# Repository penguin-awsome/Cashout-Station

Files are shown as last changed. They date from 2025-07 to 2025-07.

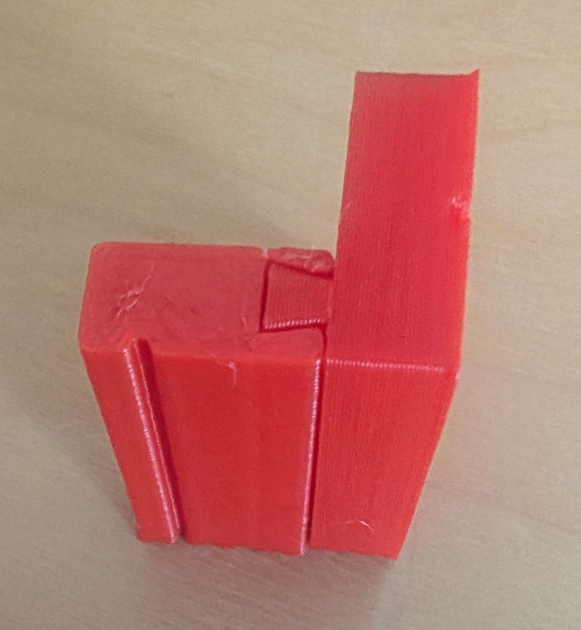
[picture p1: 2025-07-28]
Project Photos/Dovetail Test.jpg

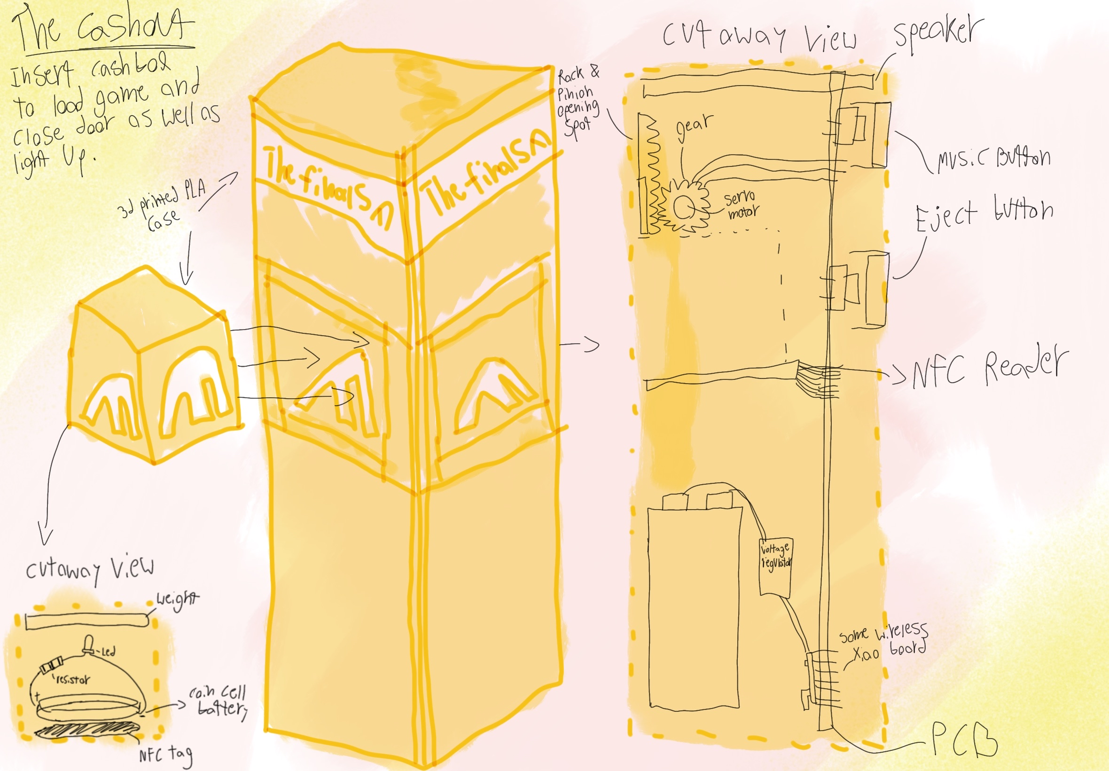
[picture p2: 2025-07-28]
Project Photos/Initial Sketch.png

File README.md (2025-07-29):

# Cashout-Station

Hello everybody, this is my latest project: The Cashout Station!

This project is inspired from my favorite video game,'The Finals', a team based FPS shooter, as well as one of my friends projects: https://github.com/jamdotjar/ULTRATERM which is another terminal inspired from a video game. In the game, the cashout is the objective point, where you insert the 'Cashbox' to begin an objective point. In my version, you insert the cahbox to launch the game and play some of the game music.

It uses a NFC Detector to detect when the cashbox has been inserted via an NFC tag, and uses a servo motor to pull the box in and close the opening for th ebox as well. It is powered by a 9v battery being stepped down to 5v to run a Xiao ESP32-C6 which is the brains of the operation. It also includes some LEDs for flair and a speaker and mini amp for the sound. It also has two buttons, one for opening up the insertion slot and one for ejecting it.

Here are some photos of the finished design:

Finished Schematic
Initial Sketch
Finished PCB
PCB Back Render
PCB Front Render

Cashout Component Layout
Cashout Full Design
Cashout Texturing

It's been really fun, albeit exausing working on this project due to a time crunch for submission time, but I'm so exited to actually build and use this thing! If you want to see the finished project, I'll be adding some photos and maybe a quick video here when completed hopefully before august 7th (The deadline)

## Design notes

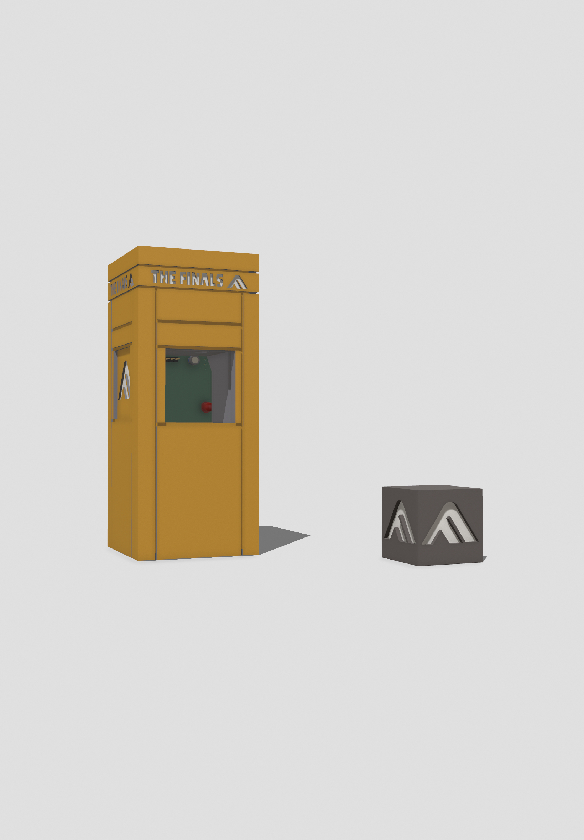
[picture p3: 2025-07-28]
Project Photos/Cashout Full Design.png

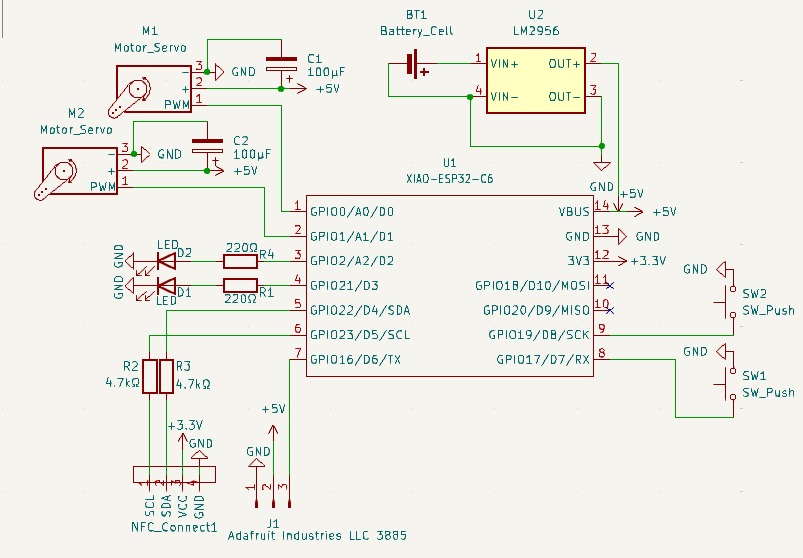
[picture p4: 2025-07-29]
Project Photos/Finished Schematic.png

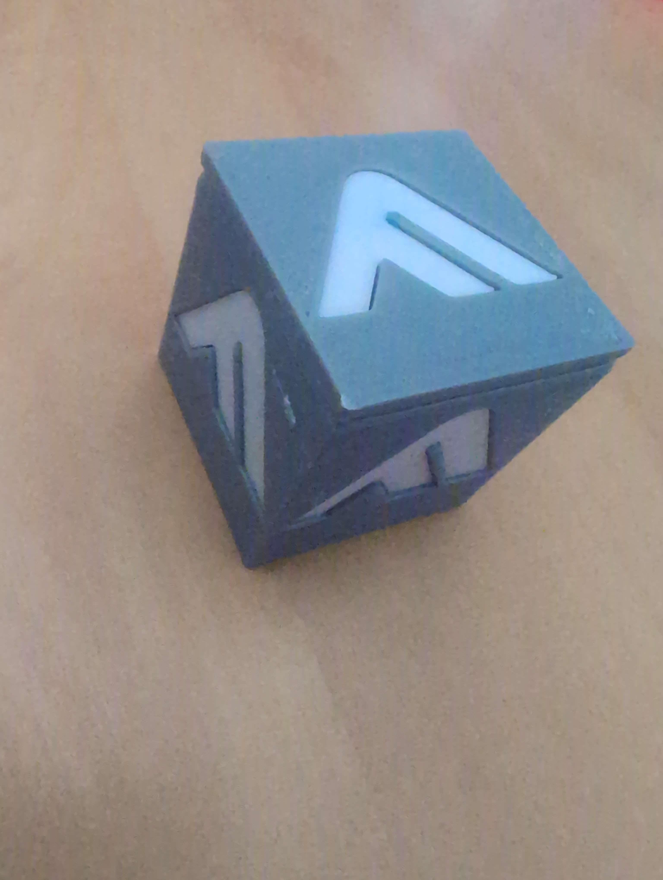
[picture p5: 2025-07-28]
Project Photos/Cashbox Prototype.jpg

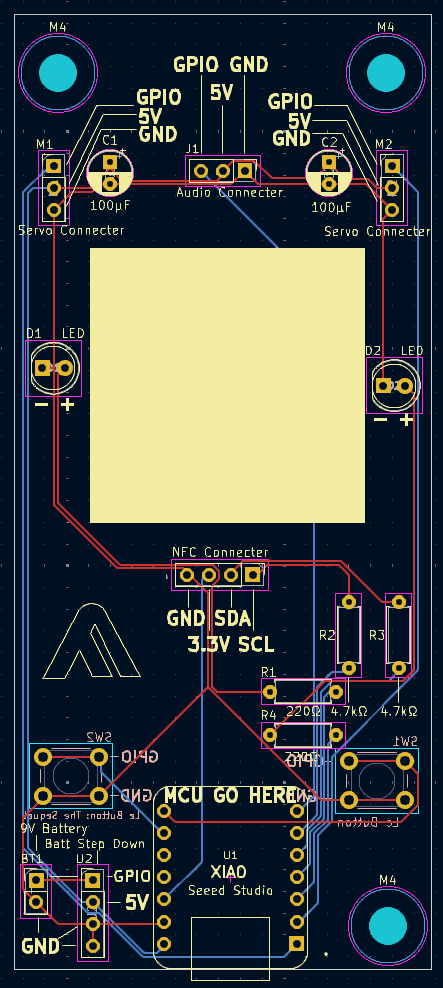
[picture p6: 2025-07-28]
Project Photos/Finished PCB.png

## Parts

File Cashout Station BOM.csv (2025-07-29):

Id | Designator | Footprint | Quantity | Designation | Price(USD) | Supplier
1 | BT1 | PinHeader_1x02_P2.54mm_Vertical | 1 | 9V Battery | $ | I own this
2 | M1,M2 | PinHeader_1x03_P2.54mm_Vertical | 2 | MG90s 360 Servo | $4.14 | https://www.aliexpress.com/item/1005008626768357.html
3 | J1 | PinHeader_1x03_P2.54mm_Vertical | 1 | 3885‎ STEMMA SPEAKER & AUDIO AMPLIFIER | $6.67 | https://www.digikey.ca/en/products/detail/adafruit-industries-llc/3885/10481842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
4 | D1,D2 | LED_D5.0mm | 1 | Red LED | $0.96 | https://www.digikey.ca/en/products/detail/dialight/5219247F/2429365
4.5 | D2 | LED_D5.0mm | 1 | White LED | $0.34 | https://www.digikey.ca/en/products/detail/inolux/INL-5AW30/7604628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
5 | R3,R2 | R_Axial_DIN0207_L6.3mm_D2.5mm_P7.62mm_Horizontal | 2 | 4.7kΩ Resistor | $5.18 (shared) | https://www.aliexpress.com/item/1005003003266002.html
6 | R1,R4 | R_Axial_DIN0207_L6.3mm_D2.5mm_P7.62mm_Horizontal | 2 | 220Ω Resistor | $5.18 (shared) | https://www.aliexpress.com/item/1005003003266002.html
7 | U2 | PinHeader_1x04_P2.54mm_Vertical | 1 | LM2596 Buck Converter | $1.53 | https://www.aliexpress.com/item/1005004904872120.html
8 | C2,C1 | CP_Radial_D5.0mm_P2.50mm | 2 | 100 µF Capacitor | $2.65 | https://www.aliexpress.com/item/32885190636.html
9 | U1 | XIAO-Generic-Thruhole-14P-2.54-21X17.8MM | 1 | XIAO-ESP32-C6 | $8.88 | https://www.aliexpress.com/item/1005007427033011.html
10 | NFC Connecter | PinHeader_1x04_P2.54mm_Vertical | 1 | PN532 NFC Module | $2.64 | https://www.aliexpress.com/item/1005007492284526.html
11 | SW2 | SW_PUSH_6mm | 2 | SPST Button | $0.54 | https://www.digikey.ca/en/products/detail/omron-electronics-inc-emc-div/B3F-1000/33150
12 | ~ | ~ | 1 | NTAG213 NFC Tag | $1.15 | https://www.aliexpress.com/item/1005008634764946.html
13 | ~ | ~ | 1 | Battery Snap Connecter | $1.48 | https://www.aliexpress.com/item/1005006208179111.html
14 | ~ | ~ | 1 | M4 Screws | $1.79 | https://www.aliexpress.com/item/4001072025844.html
14.5 | ~ | ~ | 1 | Screws | $1.88 | https://www.aliexpress.com/item/4001072025844.html
15 | ~ | ~ | 1 | Wires | $2.39 | https://www.aliexpress.com/item/1005005665978939.html
Plus | ~ | ~ | ~ | Digikey Shipping Fee | $5.82 | ~
Total | ~ | ~ | ~ | ~ | $53.22 | ~

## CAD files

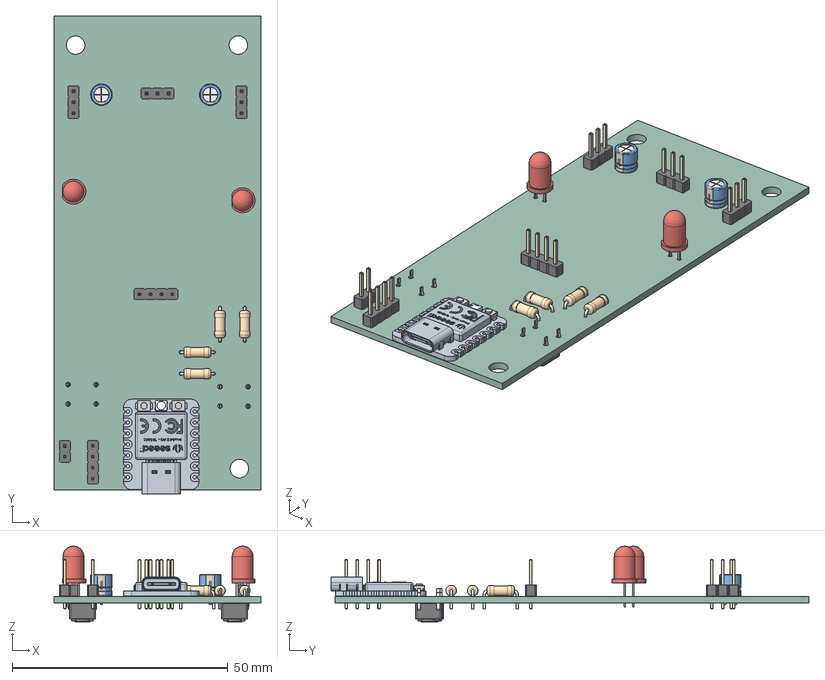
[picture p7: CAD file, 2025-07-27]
CAD/Cashout Station PCB.step
48.0 x 110.9 x 17.6 mm
PinHeader_1x02_P254mm_Vertical
PinHeader_1x03_P254mm_Vertical x 3
LED_D5.0mm x 2
R_Axial_DIN0207_L63mm_D25mm_P762mm_Horizontal x 4
PinHeader_1x04_P254mm_Vertical x 2
CP_Radial_D50mm_P250mm x 2
Seeed Studio XIAO RP2040 v26
SW_PUSH_6mm x 2
Cashout Station_PCB

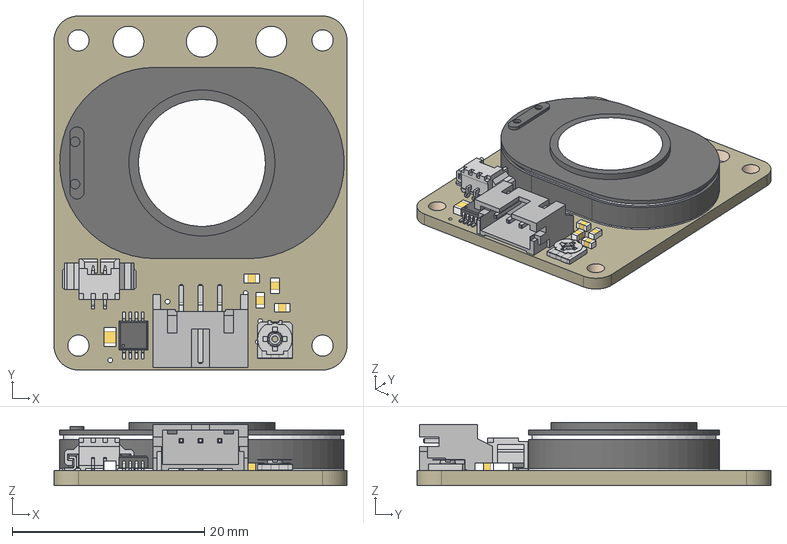
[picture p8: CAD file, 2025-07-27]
CAD/Components/3885 STEMMA Speaker rev A.step
30.5 x 36.8 x 6.57 mm
Board
PAM8302AASCR
10uF
10K trim
CON_MOLEX_2P
SPEAKER_OVAL8OHM
JST PH 3

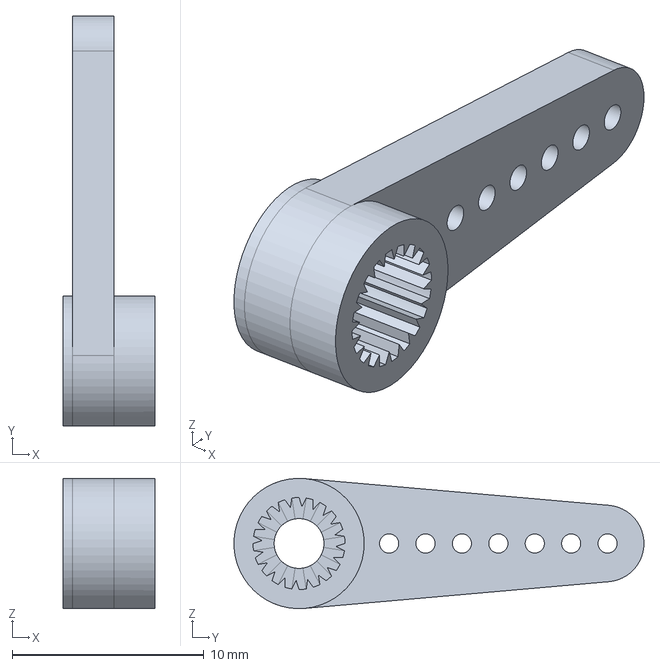
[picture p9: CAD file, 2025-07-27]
CAD/Components/MG90S_arm01.step
4.80 x 21.4 x 6.80 mm

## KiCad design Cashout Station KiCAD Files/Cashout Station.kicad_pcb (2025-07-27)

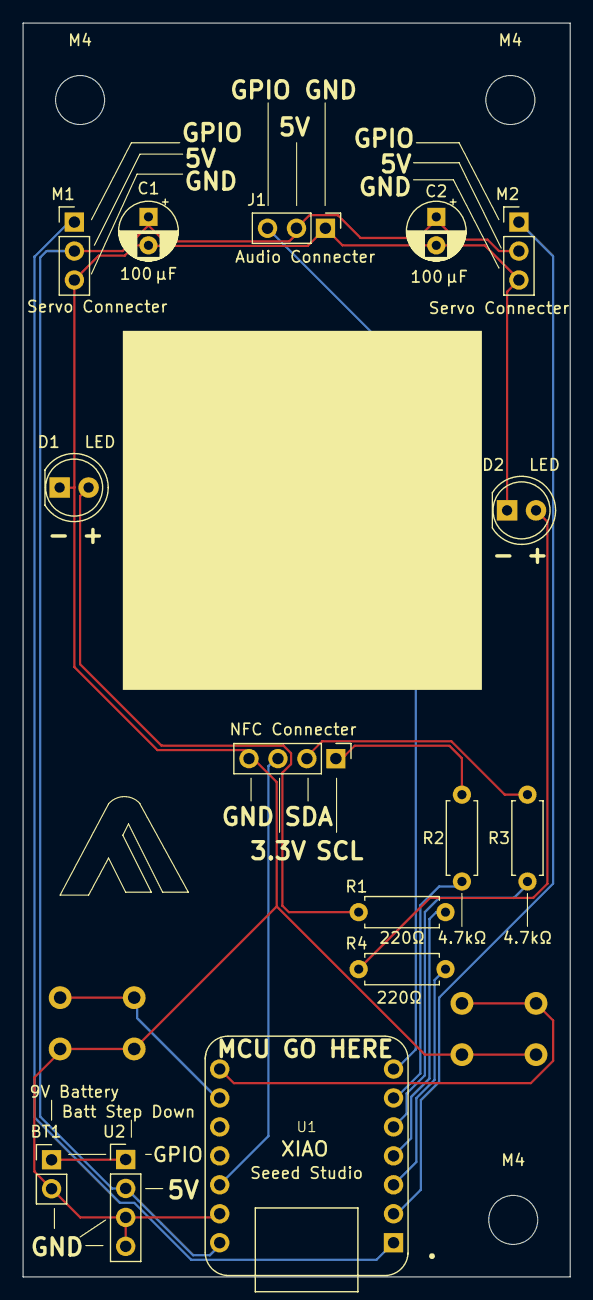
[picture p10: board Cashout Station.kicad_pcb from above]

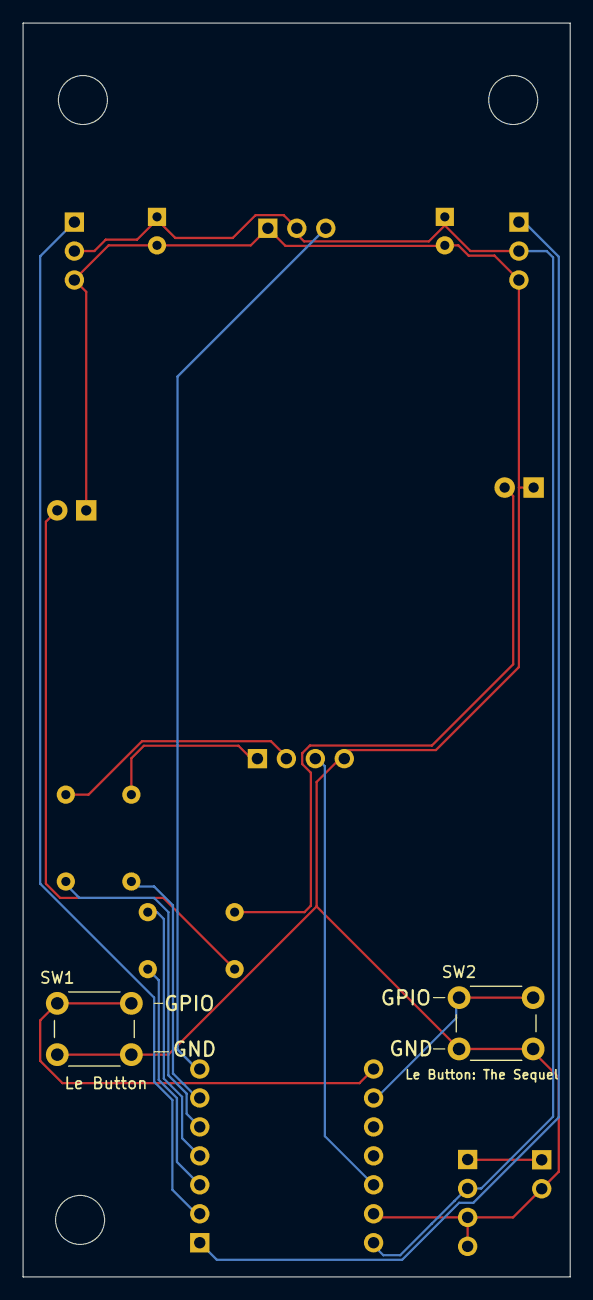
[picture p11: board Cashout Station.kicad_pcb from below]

Board: 2 copper layers, 48.0 x 110.0 mm, 20 parts (2 on the bottom side), 17 nets.

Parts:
BT1: 9V Battery; PinHeader_1x02_P2.54mm_Vertical
C1, C2: 100 µF; CP_Radial_D5.0mm_P2.50mm
D1, D2: LED; LED_D5.0mm
J1: Audio Connecter; PinHeader_1x03_P2.54mm_Vertical
M1, M2: Servo Connecter; PinHeader_1x03_P2.54mm_Vertical
M4, M4#2, M4#3: MountingHole_4.3mm_M4
NFC Connecter: PinHeader_1x04_P2.54mm_Vertical
R1, R4: 220Ω; R_Axial_DIN0207_L6.3mm_D2.5mm_P7.62mm_Horizontal
R2, R3: 4.7kΩ; R_Axial_DIN0207_L6.3mm_D2.5mm_P7.62mm_Horizontal
SW1: Le Button: The Sequel; SW_PUSH_6mm
SW2: Le Button; SW_PUSH_6mm
U1: XIAO-ESP32-C6; XIAO-Generic-Thruhole-14P-2.54-21X17.8MM
U2: Batt Step Down; PinHeader_1x04_P2.54mm_Vertical

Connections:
+3.3V: NFC Connecter.3 (VCC), U1.12 (3V3)
+5V: C1.1, C2.1, J1.2, M1.2 (+), M2.2 (+), U1.14 (VBUS), U2.2 (OUT+)
GND: BT1.2 (-), C1.2, C2.2, D1.1 (K), D2.1 (K), J1.1, M1.3 (-), M2.3 (-), NFC Connecter.4 (GND), SW1.2, SW2.2, U1.13 (GND), U2.3 (OUT-), U2.4 (VIN-)
unnamed: BT1.1 (+), U2.1 (VIN+)
unnamed: D1.2 (A), R1.1
unnamed: D2.2 (A), R4.1
unnamed: J1.3, U1.7 (GPIO16/D6/TX)
unnamed: M1.1 (PWM), U1.1 (GPIO0/A0/D0)
unnamed: M2.1 (PWM), U1.2 (GPIO1/A1/D1)
unnamed: NFC Connecter.1 (SCL), R2.2
unnamed: NFC Connecter.2 (SDA), R3.2
unnamed: R4.2, U1.3 (GPIO2/A2/D2)
unnamed: SW1.1, U1.8 (GPIO17/D7/RX)
unnamed: SW2.1, U1.9 (GPIO19/D8/SCK)
unnamed: R1.2, U1.4 (GPIO21/D3)
unnamed: R3.1, U1.5 (GPIO22/D4/SDA)
unnamed: R2.1, U1.6 (GPIO23/D5/SCL)

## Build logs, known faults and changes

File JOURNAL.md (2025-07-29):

---
Title: "Cahout Station"
Author: "James | Waddle_Penguin"
Description: "A station that launches a game with some bells and whistles"
Created On: "2025-07-17"
Total Time: ~33 hours but in a short period of time
---
# July 16th

Created a sketch of my design:


**0.4 hours**
---
# July 17th

Did some research today and started my schematic. Had trouble choosing a NFC reader but I think I found a good one. I did have to create a custom footprint though for the connection to the PCB. I think its going well but a long way to go


**1 hour**
---
# July 17th-22nd

I have relatively busy around this time, but I know if I want to get this project done soon I have to kinda lock in. I've spent my free time researching mainly, figuring out how to wire everthing up, and thinking about final assemblemy.

This included choosing a motor type, battery voltage step-down, and speaker amp. I also have chosen a good few of my parts and finished my schematic!

13ab8e70-4280-497e-8bfb-eaea7e0e1cd3

I apologize for the multi-day entry but I haven't really been getting enough done on each day to justify a full entry. Overall things are going well and I just have to:
- Check Schematic
- Assign Footprints
- Create PCB
- 3D Design
- Software
- Get Approved
- Order Parts
- Build!

It's going to be tight but I think I can do it.

**5 hours**
----
# July 23rd-27th

I have been so busy with the project I have not been journaling nearly as much as I should but here is an update on what I've been doing.

I Strated by working on and finishing my PCB which took a long time. I had to think about where everything would end up physically on the project more than I ever have before, and I also did some grphic design and other marking on the silkscreen to help me remeber what goes where and spice everything up a little, and I ended up having a lot of fun making it. I even drew the logo from the game by hand onto the board (with line tools). I can honestly say I think It's the best PCB I've made yet.

Finished PCB
PCB Front Render
PCB Back Render

Then I got started on the CAD, and the nightmare began. while it was kind of fun playing tetris with my design, figuring out how everything would actually come together was much harder. I settled on a combination of dovetail joints and some slip fits.
Dovetail Test

And as I mentioned eariler after rougly laying out all the parts I designed the basic outside structure of the design which took a while as I sketched it in the design software then extruded everything out from the sketch and made it into the final shape. I'm very happy with how it turned out although many of the dimensions are wonky due to some changes I had to make to fit everything. I also designed some other techniques to make everything fit together and print well, like the finals logo that is inserted into slots in the cashbox to give it more colour and game accuracy. I also ordered some yellow filament to make the main case and printed a verson of the cashbox

Cashout Texturing
Cashout Full Design
Cashout Component Layout
Cashbox Prototype

I also spent countless hours looking for parts online and have two orders lined up and ready to go. Also during that time I ordered my PCB which was actually not too expensive but might get here to late. I also reached out to hackclub about getting an extension on my build time. I'am now going to go work on making the final CAD changes (Adding the dovetails and buttons) and writing the code and potentially ordering parts.

Still To-Do:
- Finish off CAD
- Software
- Get Approved
- Order Parts
- Build!

** ~20 hours**
----
# June 28th-29th

Boy have I been busy, but I'm done! I think.

I ordered the rest of my parts and did a test print of my case and then made some coresponding changes, I also wrote my BOM and README. I then went on to write my software, which I will say ChatGPT played a hand in as I'm on a time crunch, but I do plan to go back and review stuff later. I set up my code for launching the game on command boot on launch as well.
Custom Startup Code

I also realized I frogot to show a photo of my schematic, so here it is!
Finished Schematic

In addition I made my file system nice and neat!
Good File Structure

Still To-Do:
- Get Approved
- Build!

Getting there! Hopefully I'm approved in time and by some miracle all of the parts make it here in time.

**13 hours**

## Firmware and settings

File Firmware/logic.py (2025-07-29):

import network
import urequests
import time
from machine import Pin, I2C, PWM
import pn532

SSID = 'WiFiSSID'
PASSWORD = 'WiFiPassword'

wlan = network.WLAN(network.STA_IF)
wlan.active(True)
wlan.connect(SSID, PASSWORD)

while not wlan.isconnected():
    time.sleep(1)
print("Connected, IP:", wlan.ifconfig()[0])

i2c = I2C(1, scl=Pin(23), sda=Pin(22), freq=400000)
pn532_module = pn532.PN532_I2C(i2c, debug=False)

ic, ver, rev, support = pn532_module.get_firmware_version()
print('PN532 firmware: {0}.{1}'.format(ver, rev))
pn532_module.SAM_configuration()

btn1 = Pin(17, Pin.IN, Pin.PULL_UP)
btn2 = Pin(19, Pin.IN, Pin.PULL_UP)

led1 = Pin(2, Pin.OUT)
led2 = Pin(21, Pin.OUT)

servo1 = PWM(Pin(0), freq=50)
servo2 = PWM(Pin(1), freq=50)

speaker = PWM(Pin(16))
speaker.duty(0)

PC_IP = '192.168.x.x'
URL = f'http://{PC_IP}:5000/trigger'

def send_trigger():
    try:
        r = urequests.post(URL)
        print("Trigger sent:", r.text)
        r.close()
    except Exception as e:
        print("Trigger failed:", e)

def set_servo_speed(servo, speed):
    neutral = 77
    max_delta = 51
    duty = int(neutral + (speed / 100) * max_delta)
    servo.duty(duty)

def beep(freq=1000, dur=200):
    speaker.freq(freq)
    speaker.duty(512)
    time.sleep_ms(dur)
    speaker.duty(0)

def siren_step(step, max_step=50, base_freq=500, freq_range=1500):
    if step < max_step // 2:
        freq = base_freq + (freq_range * step * 2) / max_step
    else:
        freq = base_freq + (freq_range * (max_step - step) * 2) / max_step
    return int(freq)

last_uid = None
nfc_cooldown_end = 0

btn2_hold_start = None
btn2_reverse_pending = False
siren_pos = 0
siren_direction = 1
max_siren_steps = 50

set_servo_speed(servo1, 0)

while True:
    now = time.ticks_ms()

    if time.ticks_ms() > nfc_cooldown_end:
        uid = pn532_module.read_passive_target(timeout=0.5)
        if uid and uid != last_uid:
            print('NFC tag:', [hex(i) for i in uid])
            beep()
            send_trigger()
            last_uid = uid
            nfc_cooldown_end = now + 5000
        elif not uid:
            last_uid = None

    if not btn1.value():
        print("Button 1 pressed")
        beep(1200, 100)
        set_servo_speed(servo1, 100)
        time.sleep(1)
        set_servo_speed(servo1, 0)
        time.sleep(0.2)
        set_servo_speed(servo1, -100)
        time.sleep(1)
        set_servo_speed(servo1, 0)
        while not btn1.value():
            time.sleep_ms(10)

    if not btn2.value():
        if btn2_hold_start is None:
            btn2_hold_start = now
            siren_pos = 0
            siren_direction = 1

        freq = siren_step(siren_pos, max_siren_steps)
        speaker.freq(freq)
        speaker.duty(300)

        siren_pos += siren_direction
        if siren_pos >= max_siren_steps:
            siren_direction = -1
            siren_pos = max_siren_steps
        elif siren_pos <= 0:
            siren_direction = 1
            siren_pos = 0

        if not btn2_reverse_pending and time.ticks_diff(now, btn2_hold_start) > 5000:
            print("Button 2 held 5s, reversing servo")
            btn2_reverse_pending = True
    else:
        speaker.duty(0)
        btn2_hold_start = None
        siren_pos = 0
        siren_direction = 1

    if btn2_reverse_pending:
        set_servo_speed(servo1, -100)
        time.sleep(1)
        set_servo_speed(servo1, 0)
        btn2_reverse_pending = False

    time.sleep_ms(10)

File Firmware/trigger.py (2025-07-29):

from flask import Flask, request
import subprocess

app = Flask(__name__)

@app.route('/trigger', methods=['POST'])
def trigger():
    print("Trigger received! Launching .exe...")
    subprocess.Popen([r"D:\Steam\steamapps\common\The Finals\start_protected_game.exe"])
    subprocess.Popen([r"D:\Steam\steamapps\common\The Finals\Discovery.exe"])
    return "OK", 200

if __name__ == '__main__':
    app.run(host='0.0.0.0', port=5000)

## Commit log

2025-07-17 Add KiCAD files back as regular folder
    [Cashout Station.kicad_pcb, Cashout Station.kicad_sch]
2025-07-24 Created PCB
    [Cashout Station PCB.step, Cashout Station.kicad_sch]
2025-07-27 PCB Updated, CAD almost complete
    [3885 STEMMA Speaker rev A.step, Cashout Station PCB.step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]
2025-07-28 Created BOM
    [Cashout Station.csv, Cashout Station.kicad_pcb]
2025-07-28 Update Cashout Station.csv
    [Cashout Station.csv]
2025-07-28 Update and rename Cashout Station.csv to Cashout Station BOM.csv
    [Cashout Station BOM.csv, Cashout Station.csv]
2025-07-28 Update Cashout Station BOM.csv
    [Cashout Station BOM.csv]
2025-07-28 Added Total Cost
    [Cashout Station BOM.csv]
2025-07-29 Added Drivers and Micropython
2025-07-29 Added CAD Files
